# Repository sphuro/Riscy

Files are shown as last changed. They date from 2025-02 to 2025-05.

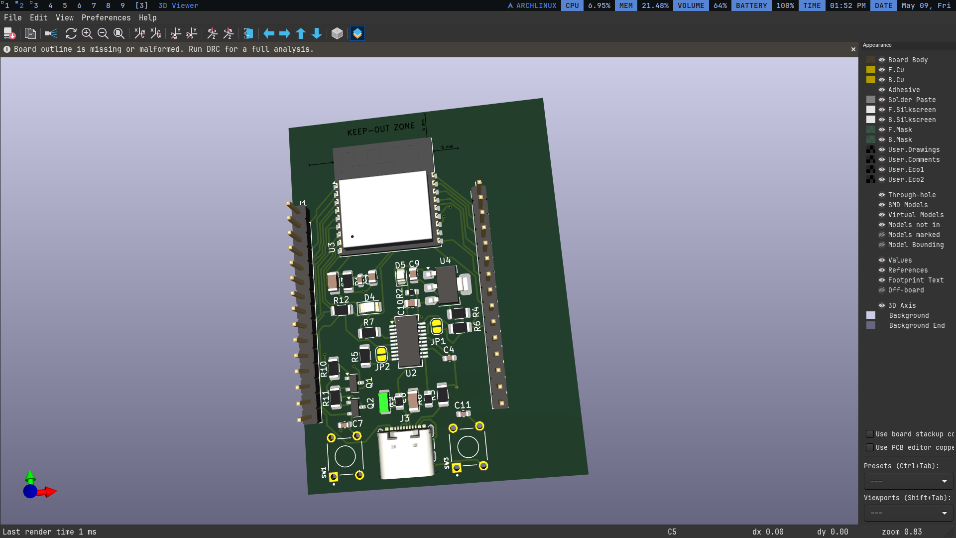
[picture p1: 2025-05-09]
2025-05-09_13-52.png

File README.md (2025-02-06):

# RISCY

I am bulding a devboard using esp32-c3 for risc 5 architechture.

## Module

- esp32-c3 02 :-
  `https://robu.in/product/espressif-esp32-c3-wroom-02-n4-module/`

## USB slave to UART

- usb to uart link x1:-
  `https://robu.in/product/ft231xs-usb-to-full-handshake-uart-ic/`
- usb c 3.1 female buy link x1 :-
  `https://sharvielectronics.com/product/16-pin-c-type-usb-connector-smd-package/`

### Automatic Bootloader mechanism

- here is the blog covering this topic:
  `https://medium.com/@kazutaka.yoshinaga/esp32-understanding-the-automatic-boot-loader-mechanism-and-truth-table-68c4dcfd081b`
- BJT link x2 :-
  `https://robu.in/product/mmbt2222-npn-transistor-pack-of-15/`

## Reset and Boot buttons

### tact-switch-tvbp06-6-0x3-5mm

- 4 pin tactile switch x2 :-
  `https://sharvielectronics.com/product/6x6x6mm-4-pin-smd-push-button-switch-black-smd-package/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`

## Programable LED

- link to buy x1 each:-
  - `https://robu.in/product/1206-surface-mount-led-white-50-pcs/`
  - `https://robu.in/product/0805-surface-mount-led-green-50-pcs/`
  - `https://robu.in/product/1210-surface-mount-led-red-50-pcs/`

## Voltage Regulator

- link to buy x1:-
  - `https://robu.in/product/ams1117-3-3v-1a-sot-223-voltage-regulator-ic-pack-of-5-ics/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`

## Schematics

Schematics

## Capacitors

- 47 pf (1206) x2
  `https://robu.in/product/1206cg470j102nt-fh-smd-multilayer-ceramic-capacitor-47-pf-1k-v-1206-3216-metric-%C2%B1-5-c0g-np0/`

- 1uf (0805) x1
  `https://robu.in/product/1uf-1000nf-50v-capacitor-0805-smd-package-pack-of-10/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`

- 0.1uf (0603) x4
  `https://robu.in/product/0-1uf-capacitor-smdc-0603/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`
- 10uf (0805) x1
  `https://robu.in/product/10uf-10000nf-25-v-capacitor-0805-smd-package-pack-of-10/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`

- 22uf (0805) x2
  `https://robu.in/product/yageo-22uf-25v-electrolytic-capacitor-5-x-11mm/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`

## Resistors

- 10k (1206) x3
  `https://robu.in/product/yageo-10k-ohm-1-4w-1206-surface-mount-chip-resistor-pack-of-50/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`
- 2k (0603) x1
  `https://robu.in/product/rc0603fr-072kl-yageo-res-thick-film-0603-2k-ohm-1-0-1w1-10w-%C2%B1100ppm-c-pad-smd-t-r/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`
- 5.1k (1206) x1
  `https://robu.in/product/rc1206fr-075k1l-yageo-res-thick-film-1206-5-1k-ohm-1-0-25w1-4w-%C2%B1100ppm-c-pad-smd-t-r/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`
- 22k (1206) x3
  `https://robu.in/product/22k-ohm-1-4w-1206-surface-mount-chip-resistor-pack-of-100/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`
- 27 (0805) x2
  `https://robu.in/product/rc0805fr-0727rl-yageo-smd-chip-resistor-27-ohm-%C2%B1-1-125-mw-0805-2012-metric-thick-film-general-purpose/`
- 1 (1206) x2
  `https://robu.in/product/1-ohm-1-4w-1206-surface-mount-chip-resistor-pack-of-100/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`

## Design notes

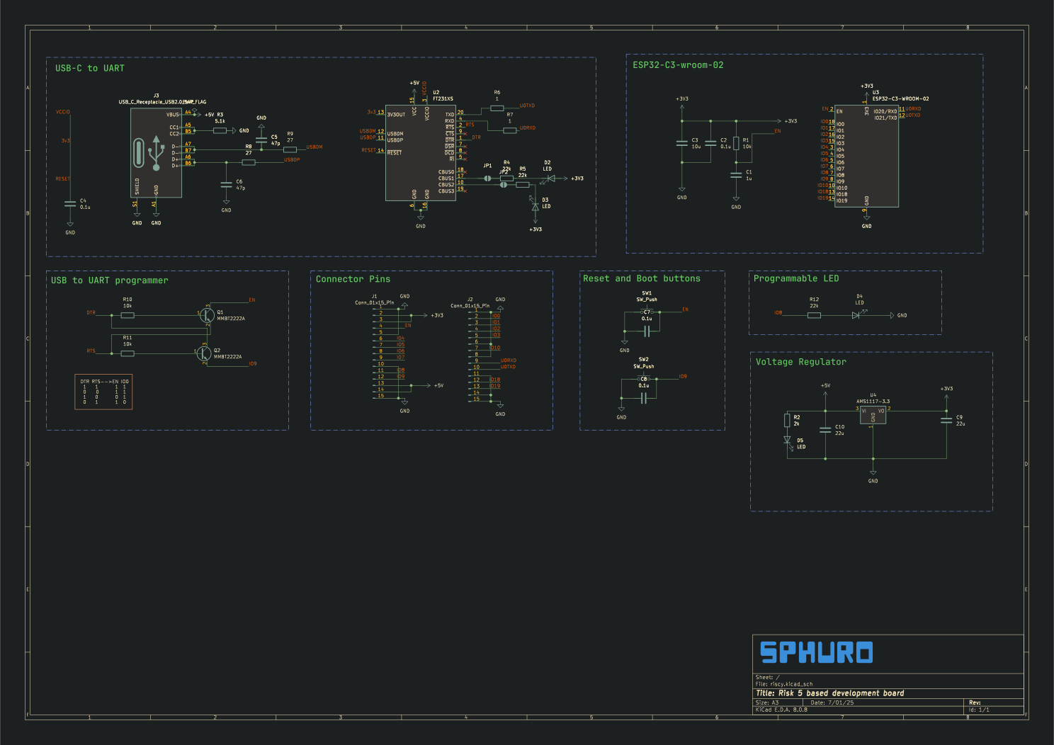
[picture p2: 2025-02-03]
sources/riscy.png

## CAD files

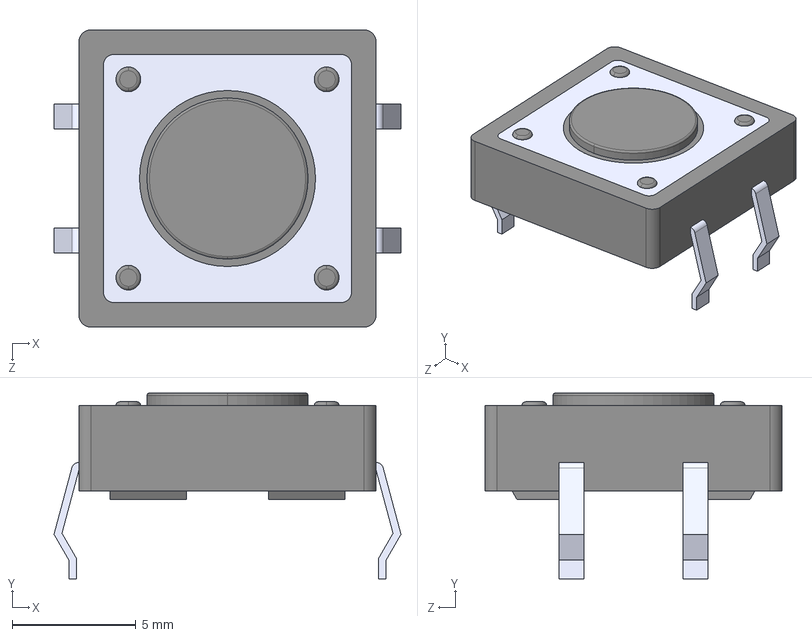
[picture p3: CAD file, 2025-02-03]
sources/VS-1213-67-160GF.step
14.0 x 7.50 x 12.0 mm

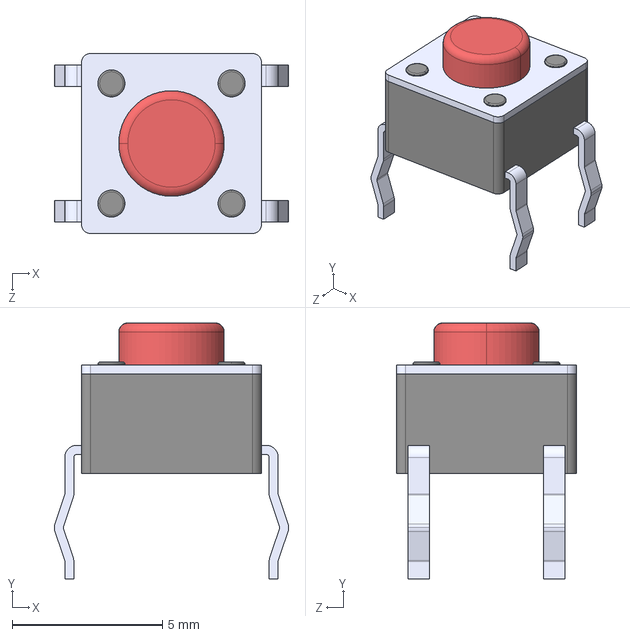
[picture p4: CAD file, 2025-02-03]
sources/1825910-6.step
7.80 x 8.52 x 5.99 mm

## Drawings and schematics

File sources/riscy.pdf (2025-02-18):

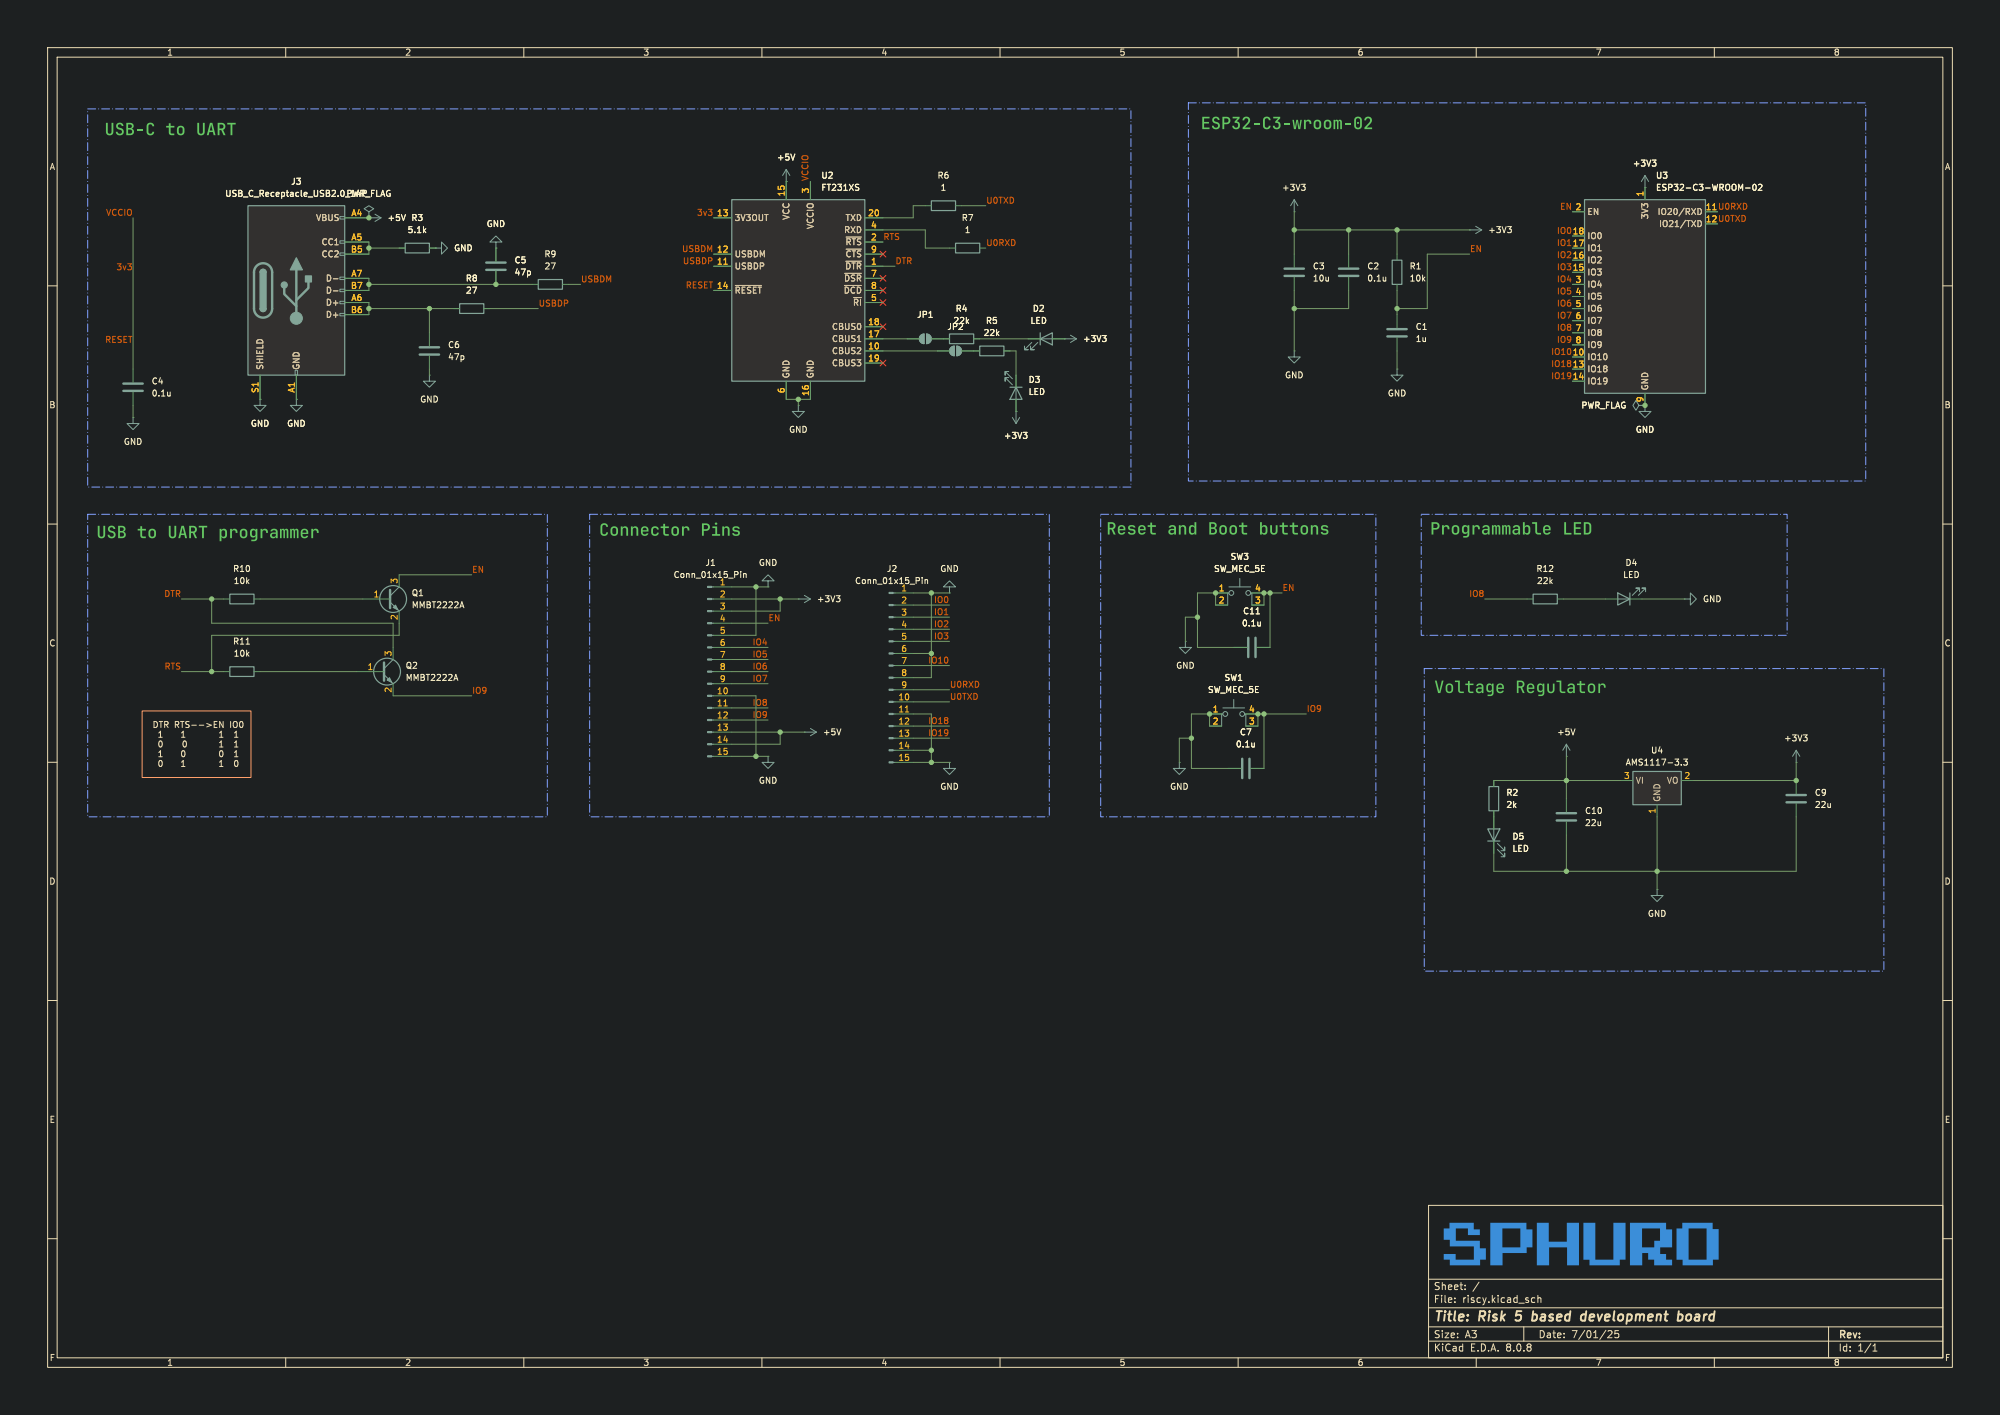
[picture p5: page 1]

File: riscy.kicad_sch Sheet: /
Id: 1/1 Title: Risk 5 based development board

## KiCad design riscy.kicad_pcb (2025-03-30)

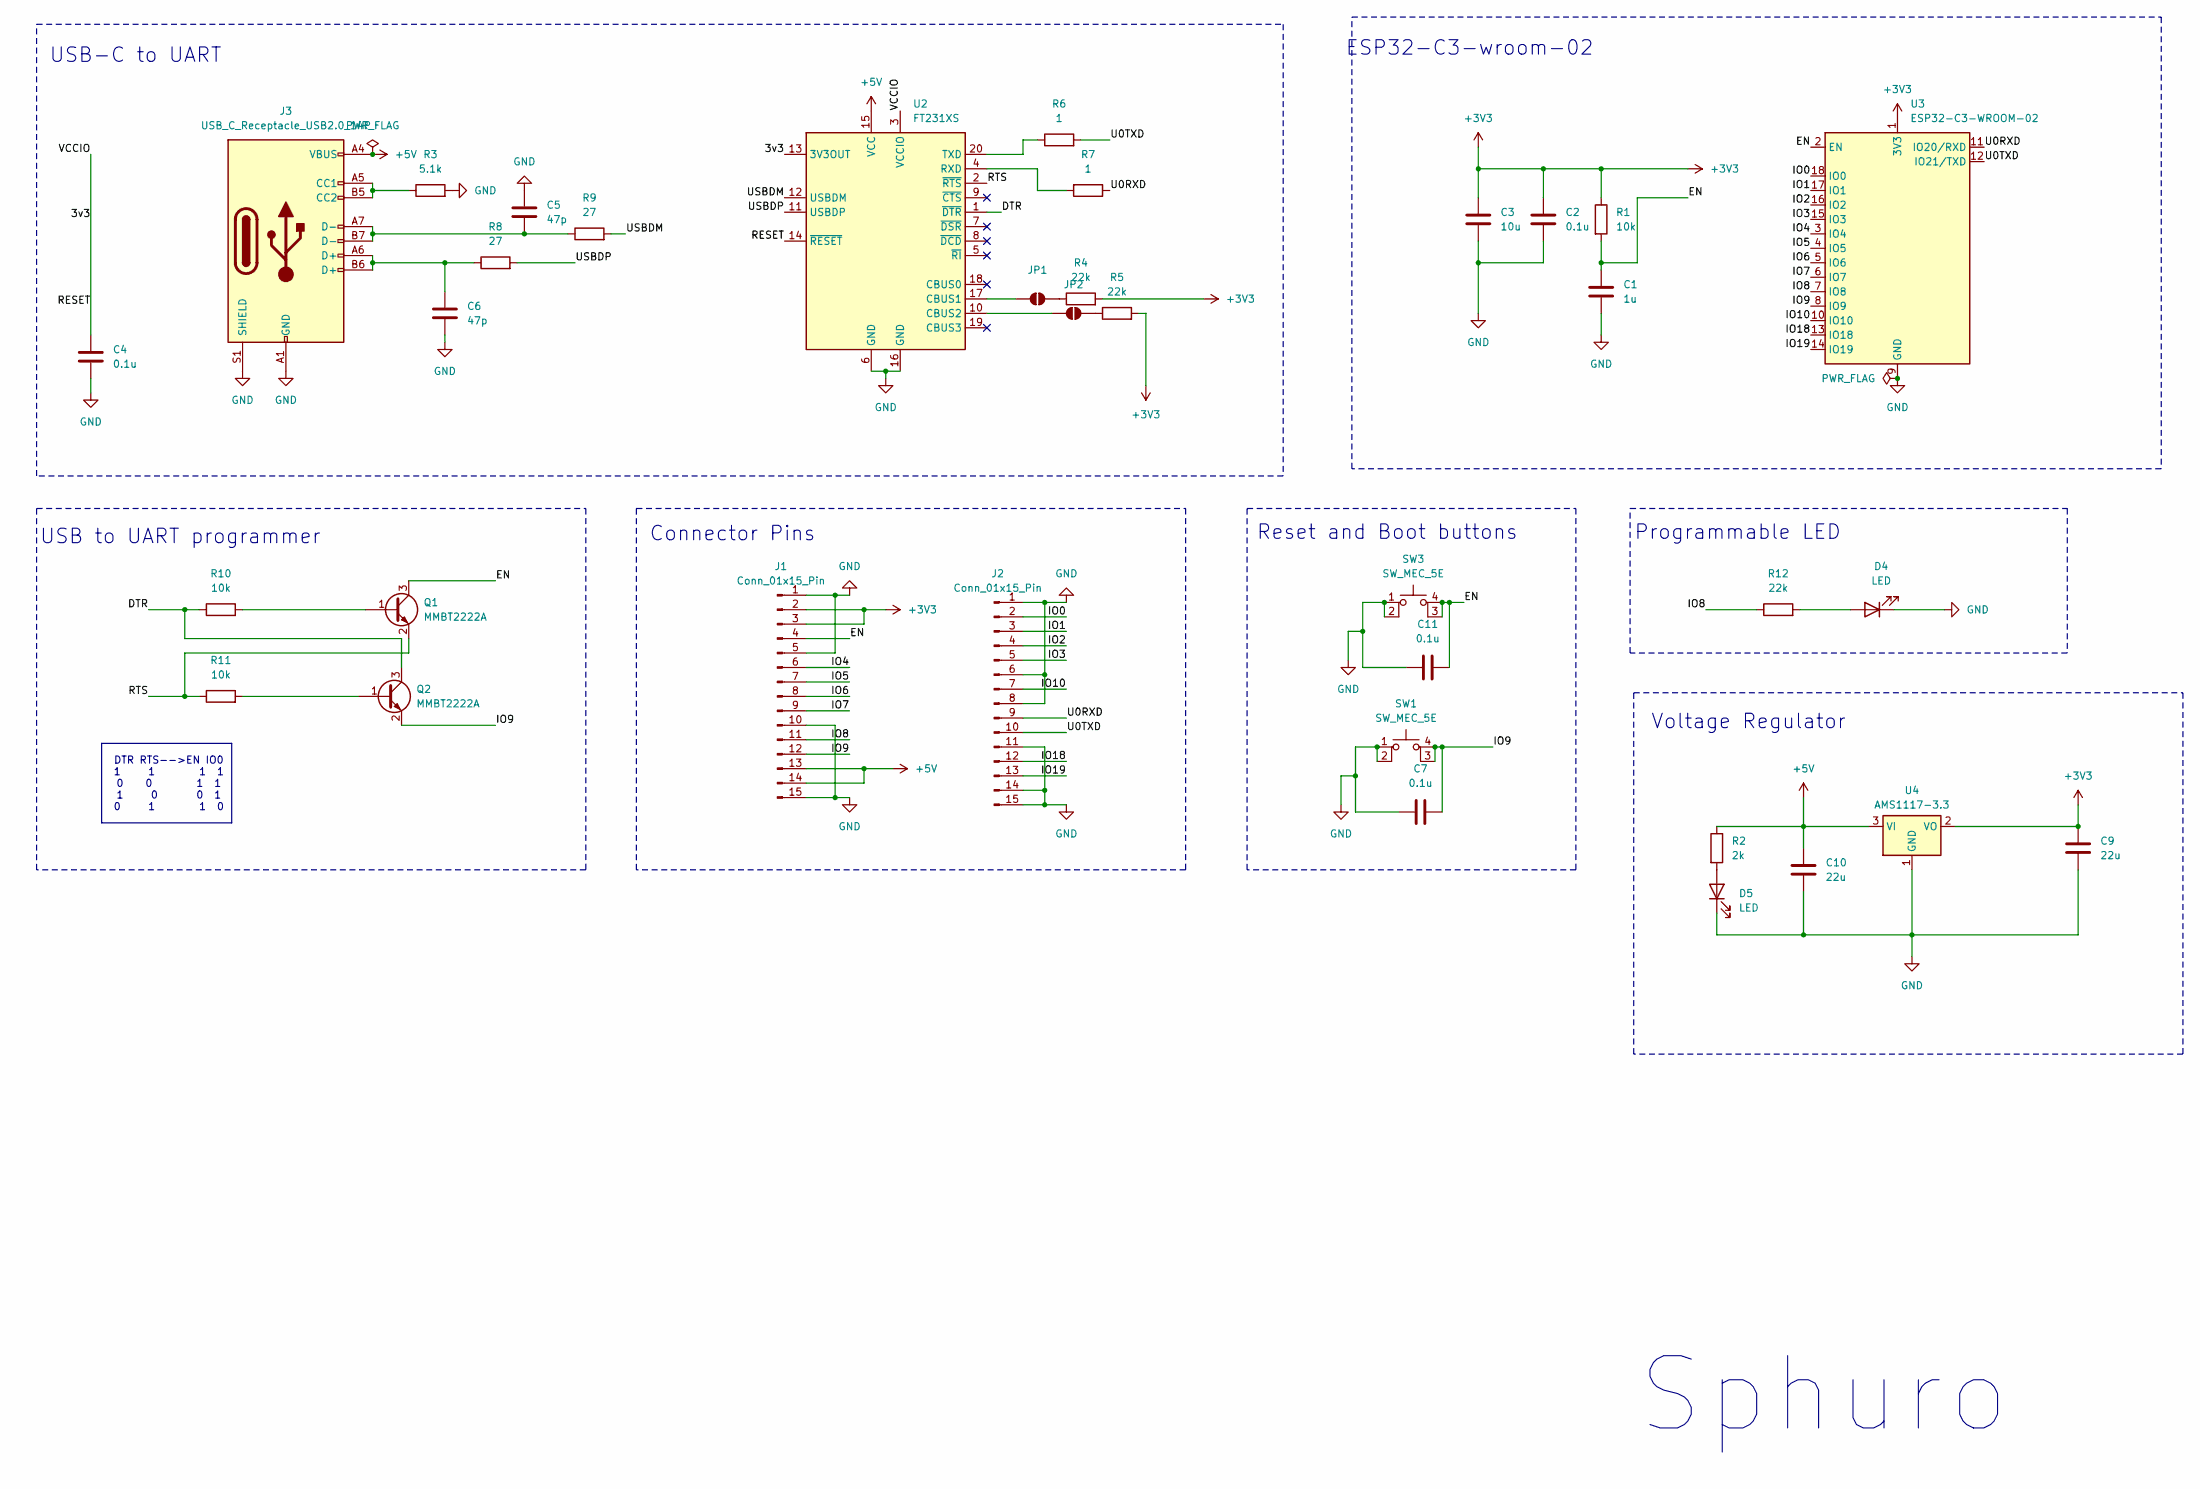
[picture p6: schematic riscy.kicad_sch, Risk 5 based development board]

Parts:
C1: 1u; C_0805_2012Metric
C2, C4, C7, C11: 0.1u; C_0603_1608Metric
C3: 10u; C_1206_3216Metric
C5, C6: 47p; C_1206_3216Metric
C9, C10: 22u; C_0805_2012Metric
D4: LED; LED_1206_3216Metric
D5: LED; LED_0805_2012Metric
J1, J2: Conn_01x15_Pin; PinHeader_1x15_P2.54mm_Vertical
J3: USB_C_Receptacle_USB2.0_14P; USB_C_Receptacle_GCT_USB4105-xx-A_16P_TopMnt_Horizontal
JP1, JP2: SolderJumper-2_P1.3mm_Open_RoundedPad1.0x1.5mm
Q1, Q2: MMBT2222A; SOT-23
R1, R10, R11: 10k; R_1206_3216Metric
R2: 2k; R_0603_1608Metric
R3: 5.1k; R_1206_3216Metric
R4, R5, R12: 22k; R_1206_3216Metric
R6, R7: 1; R_1206_3216Metric
R8, R9: 27; R_0805_2012Metric
SW1, SW3: SW_MEC_5E; SW_1825910-6-4
U2: FT231XS; SSOP-20_3.9x8.7mm_P0.635mm
U3: ESP32-C3-WROOM-02
U4: AMS1117-3.3; SOT-223-3_TabPin2

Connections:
+3V3: C2.1, C3.1, C9.1, J1.2, J1.3, R1.1, R4.2, R5.2, U3.1 (3V3), U4.2 (VO)
+5V: C10.1, J1.13, J1.14, J3.A4 (VBUS), J3.A9 (VBUS), J3.B4 (VBUS), J3.B9 (VBUS), R2.1, U2.15 (VCC), U4.3 (VI)
/3v3: C4.1, U2.3 (VCCIO), U2.13 (3V3OUT), U2.14 (~RESET)
/DTR: Q2.3 (C), R10.1, U2.1 (~DTR)
/EN: C1.1, C11.2, J1.4, Q1.3 (C), R1.2, SW3.3 (K), SW3.4 (A), U3.2 (EN)
/IO0: J2.2, U3.18 (IO0)
/IO1: J2.3, U3.17 (IO1)
/IO2: J2.4, U3.16 (IO2)
/IO3: J2.5, U3.15 (IO3)
/IO4: J1.6, U3.3 (IO4)
/IO5: J1.7, U3.4 (IO5)
/IO6: J1.8, U3.5 (IO6)
/IO7: J1.9, U3.6 (IO7)
/IO8: J1.11, R12.1, U3.7 (IO8)
/IO9: C7.2, J1.12, Q2.2 (E), SW1.3 (K), SW1.4 (A), U3.8 (IO9)
/IO10: J2.7, U3.10 (IO10)
/IO18: J2.12, U3.13 (IO18)
/IO19: J2.13, U3.14 (IO19)
/RTS: Q1.2 (E), R11.1, U2.2 (~RTS)
/U0RXD: J2.9, R7.1, U3.11 (IO20/RXD)
/U0TXD: J2.10, R6.2, U3.12 (IO21/TXD)
/USBDM: R9.2, U2.12 (USBDM)
/USBDP: R8.2, U2.11 (USBDP)
GND: C1.2, C2.2, C3.2, C4.2, C5.1, C6.2, C7.1, C9.2, C10.2, C11.1, D4.1 (K), D5.1 (K), J1.1, J1.5, J1.10, J1.15, J2.1, J2.6, J2.8, J2.11, J2.14, J2.15, J3.A1 (GND), J3.A12 (GND), J3.B1 (GND), J3.B12 (GND), J3.S1 (SHIELD), R3.2, SW1.1, SW1.2, SW3.1, SW3.2, U2.6 (GND), U2.16 (GND), U3.9 (GND), U3.19 (GND), U4.1 (GND)
unnamed: C5.2, J3.A7 (D-), J3.B7 (D-), R9.1
unnamed: C6.1, J3.A6 (D+), J3.B6 (D+), R8.1
unnamed: D4.2 (A), R12.2
unnamed: D5.2 (A), R2.2
unnamed: J3.A5 (CC1), J3.B5 (CC2), R3.1
unnamed: JP1.1 (A), U2.17 (CBUS1)
unnamed: JP1.2 (B), R4.1
unnamed: JP2.1 (A), R5.1
unnamed: JP2.2 (B), U2.10 (CBUS2)
unnamed: Q1.1 (B), R10.2
unnamed: Q2.1 (B), R11.2
unnamed: R7.2, U2.4 (RXD)
unnamed: R6.1, U2.20 (TXD)

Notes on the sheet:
USB-C to UART
DTR RTS-->EN IO0 1 1 1 1 0 0 1 1 1 0 0 1 0 1 1 0
Voltage Regulator
Reset and Boot buttons
Sphuro
Connector Pins
ESP32-C3-wroom-02
Programmable LED
USB to UART programmer

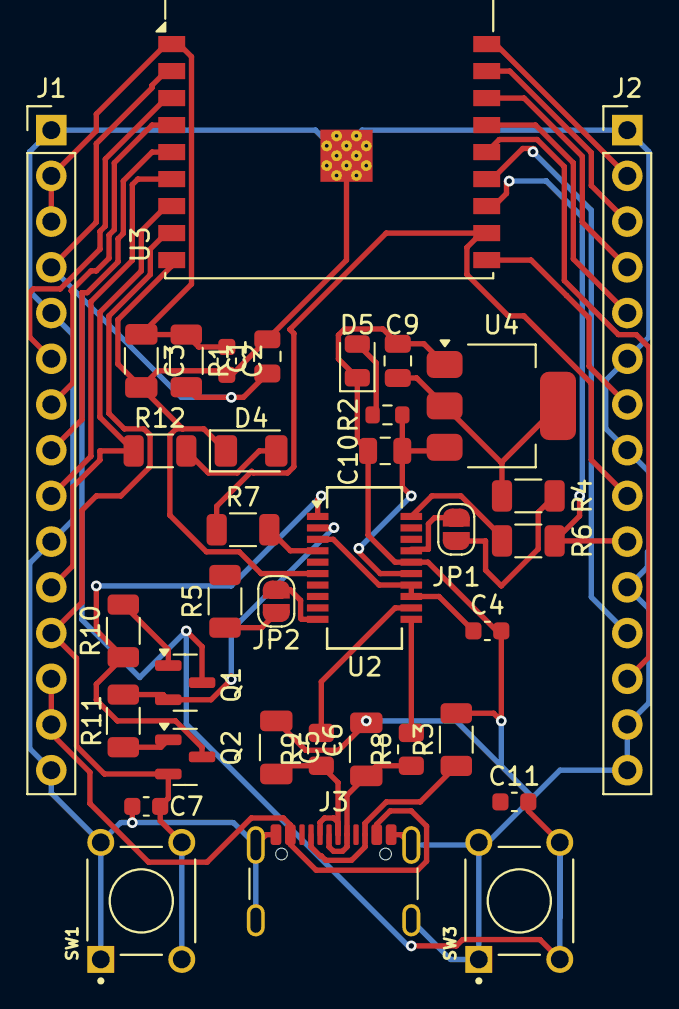
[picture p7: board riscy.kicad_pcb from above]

Board: 2 copper layers, 36 parts (0 on the bottom side), 37 nets.

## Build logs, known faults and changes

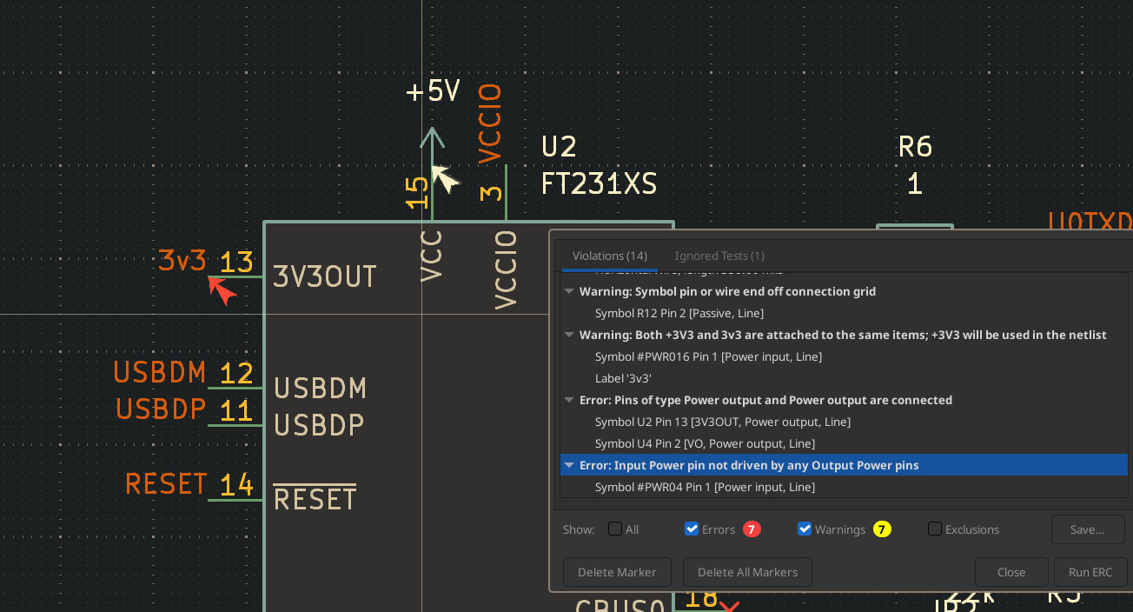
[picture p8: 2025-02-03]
sources/problem2.jpeg

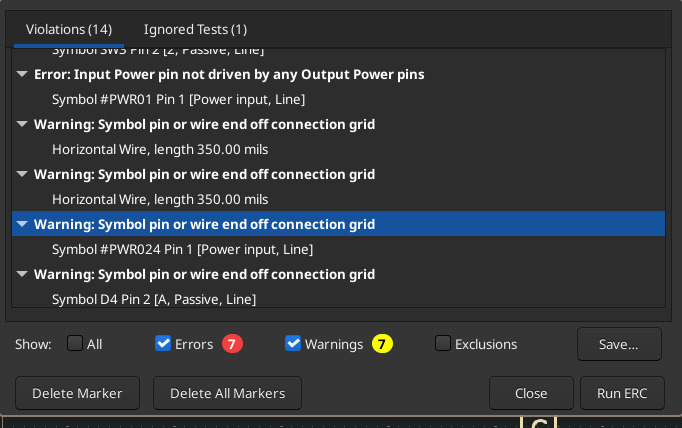
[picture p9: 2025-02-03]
sources/problem1.jpeg

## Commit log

2025-01-26 added kicad schem
    [riscy.kicad_pcb, riscy.kicad_sch]
2025-01-30 updated schematics
    [riscy.kicad_sch]
2025-01-30 schematic near compleation
2025-02-01 completed schematic
2025-02-01 schematic image
    [riscy.kicad_sch]
2025-02-01 assigned some footprints
2025-02-02 updated schematic
    [riscy.kicad_sch]
2025-02-03 fixed issues in schematicss
2025-02-03 updated schematicss
    [riscy.kicad_sch]
2025-02-03 added schematic photo
2025-02-03 added switch footprints
    [VS-1213-67-160GF.step]
2025-02-03 shcematic completed now to the pcb design:)
    [1825910-6.step, riscy.kicad_sch]
2025-02-04 pcb design started
    [riscy.kicad_pcb]
2025-02-06 updated pcb
2025-02-09 changed schematics
    [riscy.kicad_sch]
2025-02-09 changed capacitor footprint
2025-03-04 making pcb
    [riscy.kicad_pcb]
2025-03-24 updated design
    [riscy.kicad_pcb]
2025-05-09 added screenshots of pcb design
